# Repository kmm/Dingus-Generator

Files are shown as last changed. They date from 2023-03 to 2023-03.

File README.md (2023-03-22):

# Dingus-Generator

---
> Snap-together ball and socket camera mounting dingii

## Overview
OpenSCAD scripts to generate snap-together articulated ball and socket dinguses for repositionable mounting of small cameras, lights, and instruments.

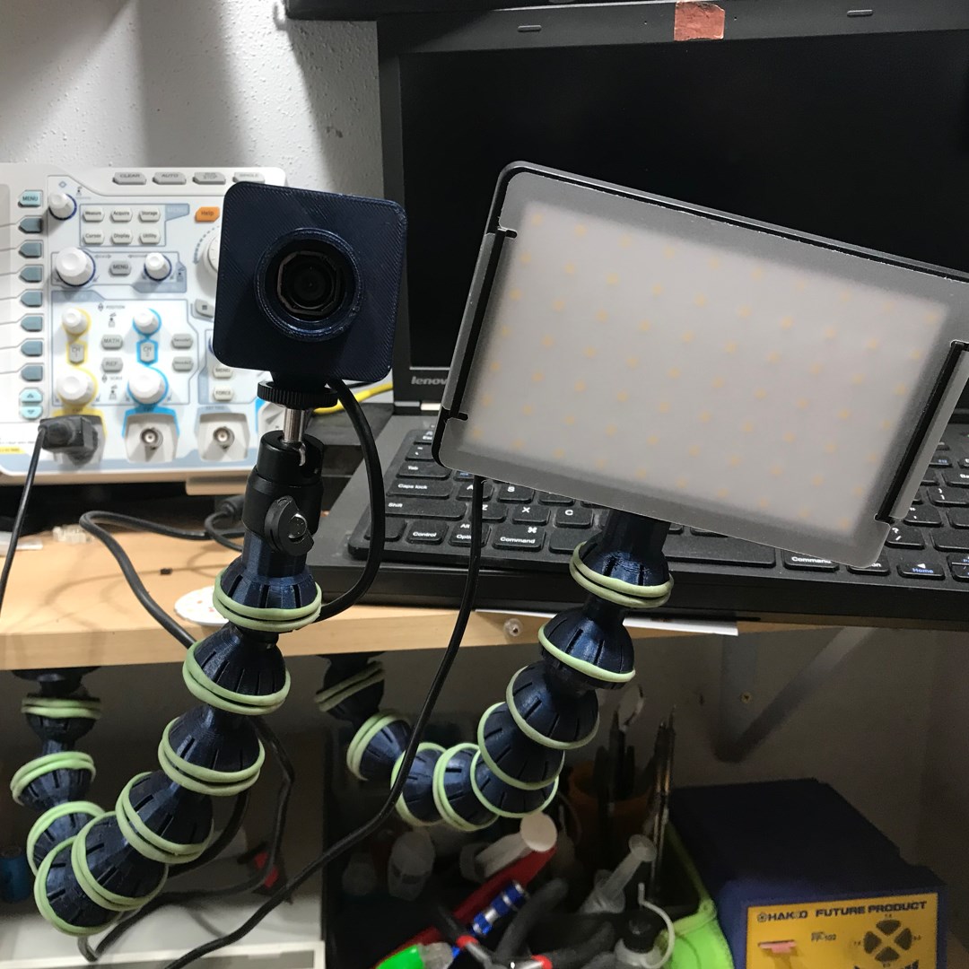
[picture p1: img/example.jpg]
Example Dingus System
  

## Usage

- **Dingus.scad**
	- Generates articulating ball and socket dingus segments
- **FlangeBase.scad**
	- Generates terminal dingus with flange mount and ball suitable for screwing or sticking to surfaces.
- **CamMount.scad**
	- Generates terminal dingus with socket to provide a 1/4-20 tripod mounting stud to mount stuff on.

Most parameters you need are exposed in the OpenSCAD customizer, modify them as you see fit to match your dingus requirements. I find keeping the radial resolution ($fn) fairly coarse helps with grip.

Don't expect these to support a DSLR, but they will hold webcams and cheap lights and I've had them deployed on my workbench in this capacity for around a year with no breakage.

Use castration bands (yes, really, the things used to nullify goats; a kit with the installation tool is less than $20) around the grooves to increase grippyness. Colophony dissolved in alcohol or liquid rosin-activated flux
applied to the ball and allowed to completely dry also will increase grip for holding slightly heavier apparatus.

I recommend printing these with the socket end up since they tend to detach from the build plate. The ball may be a bit misshapen when printed on support material but
this doesn't substantially affect performance.

PETG is about the only option here, PLA's brittleness and relatively poor layer adhesion makes the sockets too fragile to accept the ball. More exotic materials may be even better but I haven't tried any.

The default sizing for the camera mount terminal dingus will accept a piece of 1/4-20 threaded rod, and can be made oversize to fit a whole bolt.

## References
[OpenSCAD](https://openscad.org/)

## License

MIT

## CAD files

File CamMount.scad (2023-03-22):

// Nominal diameter of the ball
ballDiameter = 24;

// Nominal diameter of the socket
socketDiameter = 24;
// Wall thickness of the socket
socketWall = 4;
outerDiameter = socketDiameter + (socketWall*2);
socketCutDepthFactor = 0.35;
// Depth of the cut made into the socket sphere in relation to the full OD
socketCutDepth = outerDiameter * socketCutDepthFactor;
// Relief cut depth relative to socket cut plane
socketReliefDepth = 15;
// Number of socket relief cuts
socketReliefs = 9;
// Width of the socket relief cuts
socketReliefWidth = 1.5;
internalReliefXOffset = 0.75;
internalReliefZOffset = (socketDiameter / 2) * 0.9;
internalReliefDiameter = 3.0;

// Girth of the shaft
shaftDiameter = 20;
// Length of the shaft
shaftLength = 25;
// Diameter of the ring capture notch cut into the socket
ringNotchDiameter = 3.0;
// Tune this to change the ring notch cut depth, more +offset = shallower
ringNotchOffset = ringNotchDiameter / 6;
// P hole diameter
pHoleDiameter = 6;
// P hole countersink diameter
pHoleCountersinkDiameter = 12;
// P hole countersink depth
pHoleTipCountersinkDepth = 1.0;
pHoleSocketCountersinkDepth = 4.0;

// Preview mode (faster, visualizes cuts but does not perform them)
previewDingus = false;
enablePHole = true;
enableReliefCuts = true;
enableInternalReliefs = true;
enableExternalCuts = true;

// Z-level of the end of the dingus
tip = shaftLength+ballDiameter/2;
// Z-level of the base of the dingus after the socket cut
base = -(outerDiameter/2) + socketCutDepth;

socketCutPlane = (-1/2 * outerDiameter) + socketCutDepth;
cutColor = "white";

$fn = 16;

function chordLength(r, t) = 2 * sqrt(abs(r)^2 - abs(t)^2);
// Calculate chord given diameter and offset from center, returns 1/2 chord length
function radialChord(d, t) = sqrt(abs(d/2)^2 - abs(t)^2);

module dingus() {
    union() {
        // Construct the basic dingus
        // Shaft
        color("skyblue", 1)
        cylinder(h = shaftLength, d=shaftDiameter);
        // Socket
        color("skyblue", 1)
        sphere(d=outerDiameter);    
    }
};

module socketCut() {
    // Cut the bottom off the base sphere (socket)
    translate([0, 0, -outerDiameter/2 + socketCutPlane])
    color(cutColor, 0.25)
    cube([outerDiameter + 1, outerDiameter + 1, outerDiameter], center=true);    
    // Cut the socket internal volume
    color("lime", 1)
    sphere(d=socketDiameter, $fn=100);
}

module reliefCuts() {
    // Cut reliefs around the socket
    for(r = [0 : 360/socketReliefs : 360]) {
        rotate([0, 0, r])
        translate([-1 * (socketReliefWidth/2), 0, socketCutPlane])
        color(cutColor, 0.25)
        cube([socketReliefWidth, socketDiameter/2+socketWall+4, socketReliefDepth]);
    }    
}

module internalReliefCuts() {
    // Cut internal reliefs
    color("orange", 1)
    rotate_extrude(convexity=3)
    translate([radialChord(socketDiameter, internalReliefZOffset/1.5)-internalReliefXOffset, internalReliefZOffset/1.5, 0])
    circle(d=internalReliefDiameter);
    
    color("orange", 1)
    rotate_extrude(convexity=3)
    translate([radialChord(socketDiameter, internalReliefZOffset/9)-internalReliefXOffset, internalReliefZOffset/9, 0])
    circle(d=internalReliefDiameter);      
}

module externalCuts() {

    // Cut the ring capture notch
    color(cutColor, 0.25)
    rotate_extrude(convexity=3)
    translate([outerDiameter/2+ringNotchOffset, -2, 0])
    circle(d=ringNotchDiameter);
    // Cut the ring capture notch
    
    color(cutColor, 0.25)
    rotate_extrude(convexity=3)
    translate([outerDiameter/2+ringNotchOffset, 2, 0])
    circle(d=ringNotchDiameter);    
        
    // Cut socket edge concave
    color("red", 0.25)
    rotate_extrude(convexity=3)
    translate([radialChord(socketDiameter, socketCutPlane), socketCutPlane, 0])
    circle(d=ringNotchDiameter);    
    

}

module pHoleCuts() {
    // Passthrough hole
    color(cutColor, 0.5)
    linear_extrude(tip+1)
    circle(d=pHoleDiameter);
    
    // Socket countersink
    color("cyan", 0.25)
    linear_extrude((socketDiameter/2) + pHoleSocketCountersinkDepth)
    circle(d=pHoleCountersinkDiameter);
    
    // Tip countersink
    color("gold", 0.25)
    translate([0, 0, tip-pHoleTipCountersinkDepth])
    linear_extrude(pHoleTipCountersinkDepth*2)
    circle(d=pHoleCountersinkDiameter);
}

if(previewDingus) {
    difference() {
        dingus();
        socketCut();
    }
    pHoleCuts();
    externalCuts();
    internalReliefCuts();
}
else {
    difference() {
        difference() { 
            difference() {
                dingus();
                socketCut();
            }
            if(enablePHole) 
            pHoleCuts();
            if(enableExternalCuts)
            externalCuts();
            if(enableInternalReliefs)
            internalReliefCuts();
        }
        if(enableReliefCuts)
        reliefCuts();
    }    
}

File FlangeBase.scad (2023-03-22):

// Nominal diameter of the ball
ballDiameter = 24;
// Girth of the shaft at the knob
shaftDiameter = 8;
// Length of the shaft
shaftLength = 30;
// Diameter of the flange
flangeDiameter = 40;
// Thickness of the flange
flangeThickness = 6;
// Flange Hole diameter
flangeHoleDiameter = 4;
// Flange Countersink Diameter
flangeCountersinkDiameter = 6;
// Flange Countersink Depth
flangeCountersinkDepth = 1;

shaftBaseDiameter = flangeDiameter - (flangeCountersinkDiameter * 2) - (flangeDiameter / 10);

// Preview mode (faster, visualizes cuts but does not perform them)
previewDingus = true;

// Z-level of the end of the dingus
tip = shaftLength+ballDiameter/2;

cutColor = "white";

$fn = 25;

function chordLength(r, t) = 2 * sqrt(abs(r)^2 - abs(t)^2);
// Calculate chord given diameter and offset from center, returns 1/2 chord length
function radialChord(d, t) = sqrt(abs(d/2)^2 - abs(t)^2);

module dingus() {
    union() {
        // Construct the basic dingus
        // Shaft
        color("skyblue", 1)
        cylinder(h = shaftLength, d1=shaftBaseDiameter, d2 = shaftDiameter);
        // Ball
        color("skyblue", 1)
        translate([0, 0, shaftLength])
            sphere(d=ballDiameter);  
    }
};

module flange() {
    difference() {
        translate([0, 0, -flangeThickness])
        cylinder(flangeThickness, d = flangeDiameter);
        union() {
        for(r = [0 : 360/4 : 360]) {
            rotate([0, 0, r]) {
                translate([flangeDiameter/2 - flangeHoleDiameter, 0, -flangeThickness]) {
                    cylinder(h = 10, d=flangeHoleDiameter);
                }
                translate([flangeDiameter/2 - flangeHoleDiameter, 0, -flangeCountersinkDepth]) {
                    cylinder(h = flangeCountersinkDepth+0.1, d1=flangeHoleDiameter, d2=flangeCountersinkDiameter);
                }
            }
        }
    }
}
}


if(previewDingus) {
        dingus();
        flange();
}
else {
    dingus(); 
}

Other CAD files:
Dingus.scad
